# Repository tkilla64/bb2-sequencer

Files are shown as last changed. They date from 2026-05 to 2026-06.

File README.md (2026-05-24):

# bb2-sequencer
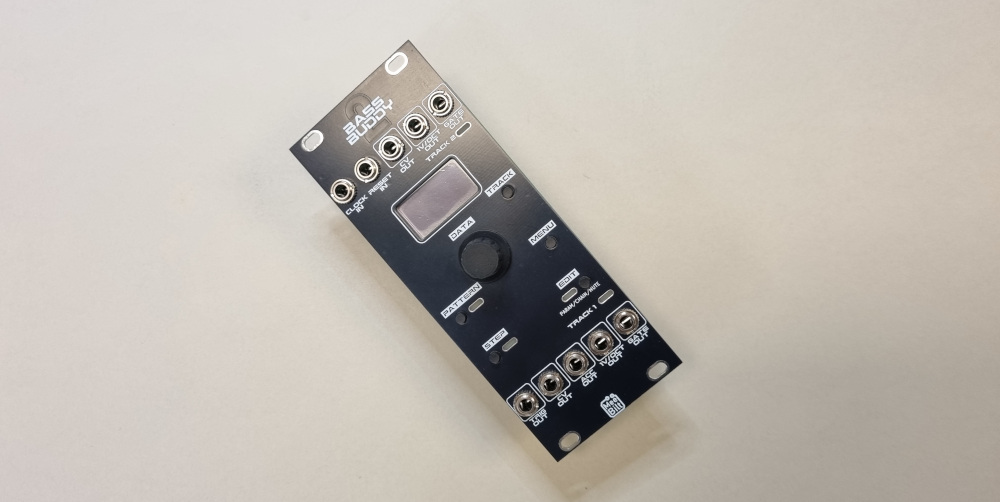
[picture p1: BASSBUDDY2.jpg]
bb2 image

BassBuddy2 Sequencer is a dual 16-step sequencer for Eurorack. It is designed to be used with the Erica Synths Bassline DIY, but any Eurorack synth-voice can be used.

### Inputs
CLOCK input with 1 clock-pulse per step the advance is made on the low-to-high transition of the signal.  
RESET input which resets the current pattern to step 1 at the low-to-high transition. RESET input can be reconfigured to a Clock for Track2 sequencer.

### Track1 Outputs
GATE output that is held high during the high period of the CLOCK input signal.  
1V/OCT output with note pitch voltage (0.0-4.916V, C-0 to B-4)  
VCF CV output with programmable voltage 0-5V  
ACCENT CV output with programmable 0-5V  
TRIG output programmable 5V pulse 

### Track2 Outputs
GATE output that is held high during the high period of the CLOCK input signal.  
1V/OCT output with note pitch voltage (0.0-4.916V, C-0 to B-4)  
VCF CV output with programmable voltage 0-5V   

### Steps and Patterns
A total of 60 patterns with pattern length 1-16 steps where each step have the following programmable functions:
 - Note pitch (or rest)
 - Tie note to next step
 - Slide to next step
 - VCF CV voltage

### User Interface
Consists of the 0.96" OLED, 5 pushbuttons, 5 LEDs and a rotary encoder with a pushbutton switch.

PATTERN, STEP and EDIT buttons selects and edits patterns. Possible to chain patterns.

TRACK button selects between tracks (sequencer).

MENU button accesses the following functions:
 - NEW: create a new empty pattern
 - SAVE: Save patterns and settings to EEPROM
 - LOAD: Load patterns and settings from EEPROM
 - COPY: Copy pattern
 - CLK:  Configure CLOCK and RESET
 - SEQ:  Set startup pattern after power on
 - CAL:  Calibrate the the dual-PWM outputs
 - TUN1: Output a note on 1V/OCT outputs
 - FACT: Reset patterns and settings to factory settings

### Supply
10-pin power connector:  
+12 VDC @ 60 mA  
-12 VDC @ 10 mA

### Dimensions
Height: 3U  
Width:  10HP  
Depth:  30 mm

### YouTube video
[Eurorack DIY: Bass Buddy II - Bigger and Better](https://youtu.be/oqoJV0XfK5c)

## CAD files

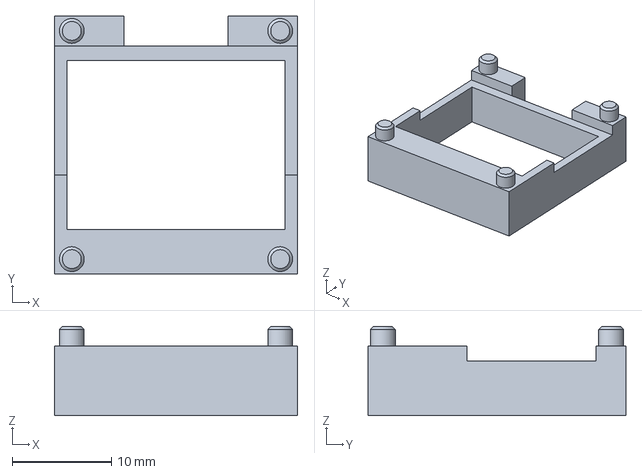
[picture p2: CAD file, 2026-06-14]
mech/OLED_bracket.FCStd
24.5 x 26.0 x 9.00 mm

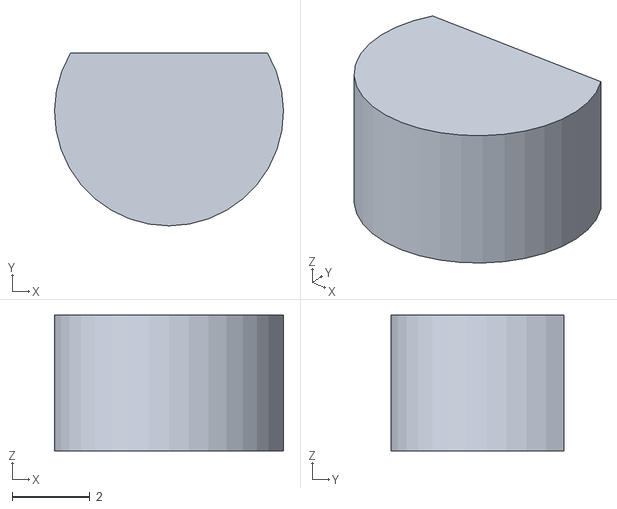
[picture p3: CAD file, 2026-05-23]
mech/shims_encoder_knob_v1.stl
5.90 x 4.45 x 3.50

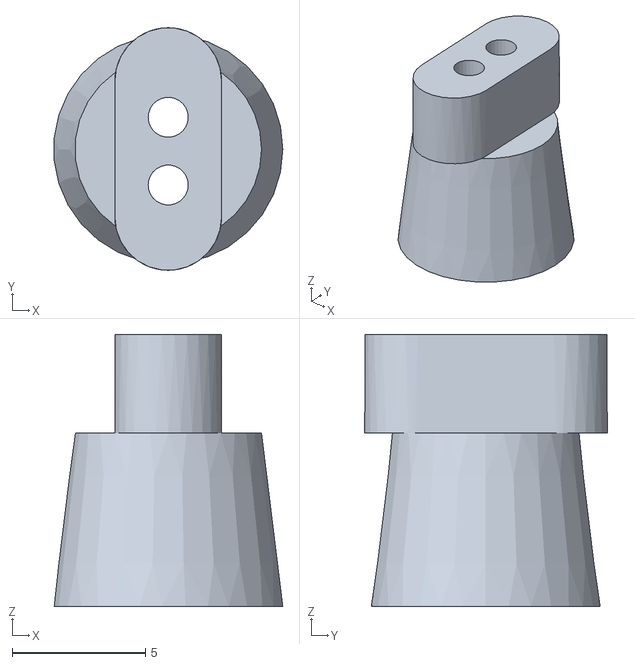
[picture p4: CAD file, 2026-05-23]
mech/2pin_LED_holder_v1.stl
8.57 x 9.10 x 10.2

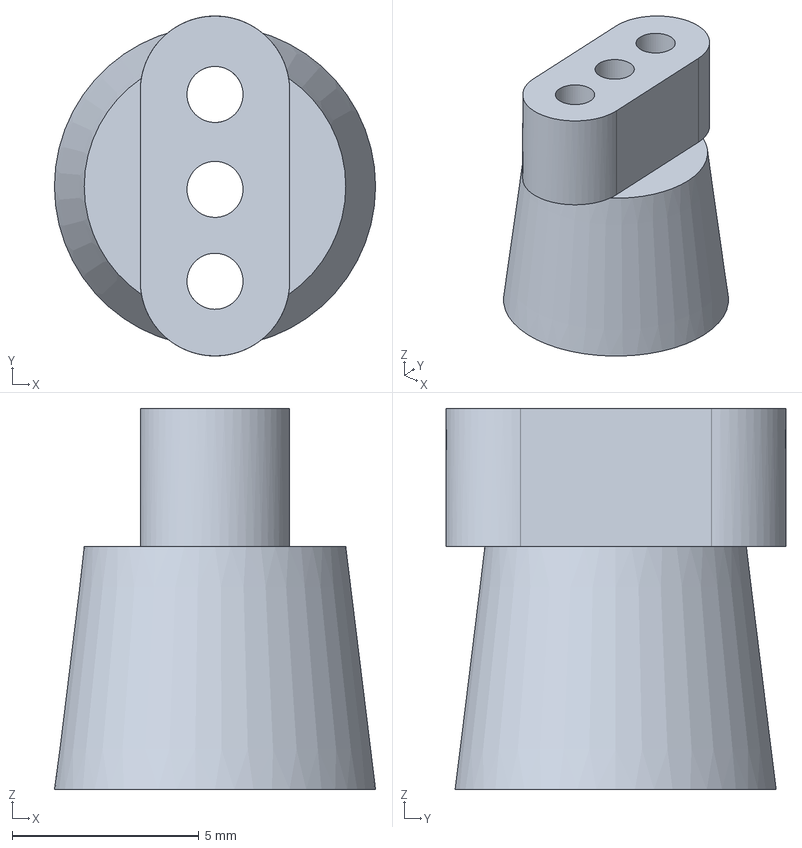
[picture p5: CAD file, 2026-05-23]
mech/3pin_LED_holder.FCStd
8.60 x 9.10 x 10.2 mm

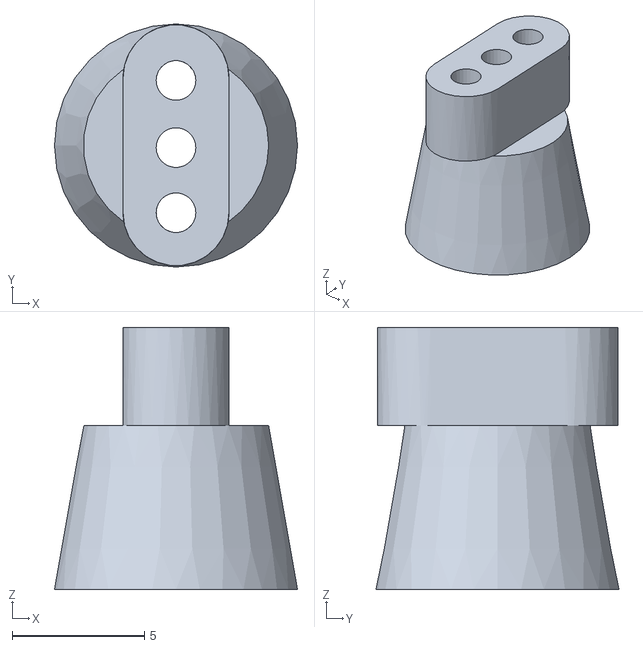
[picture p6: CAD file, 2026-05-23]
mech/3pin_LED_holder_v1.stl
9.19 x 9.19 x 9.90

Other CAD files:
mech/OLED_bracket_v1.stl
mech/shims_encoder_knob.FCStd
mech/2pin_LED_holder.FCStd

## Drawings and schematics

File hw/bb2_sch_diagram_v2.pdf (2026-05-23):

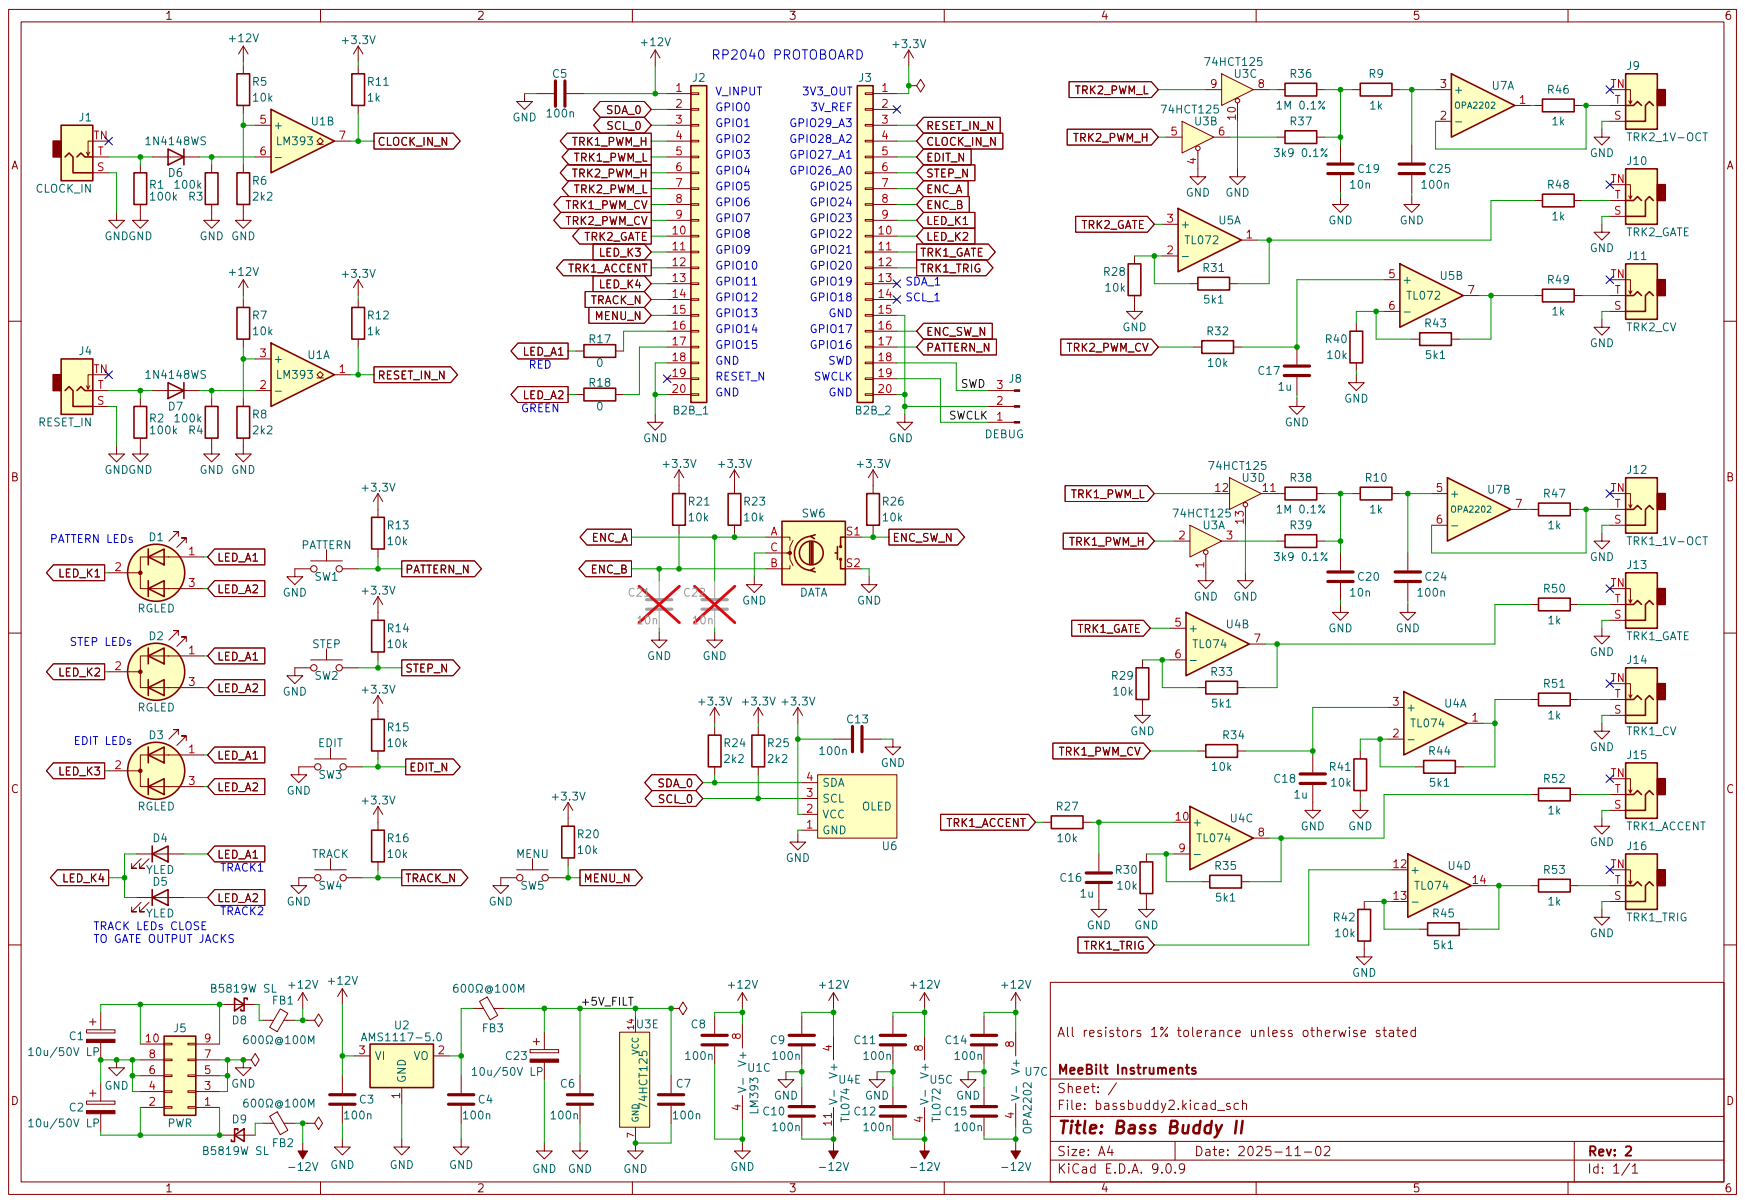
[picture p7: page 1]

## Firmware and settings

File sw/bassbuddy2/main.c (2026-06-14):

/**
 * @file main.c
 * 
 * Bass Buddy II (by Tommy Killander, tkilla64, MeeBilt):
 *
 * FEATURES:
 *  - CLOCK and RESET inputs 
 *  - Two tracks with separate outputs:
 *    * Track1: GATE, 1V/OCT, ACC, CV, TRIG
 *    * Track2: GATE, 1V/OCT, CV
 *  - 128x64 OLED Display
 *  - Control: 5 buttons and Encoder knob
 *  - EEPROM for calibration and parameter storage (4096 bytes)
 * 
 * IDE: Visual Studio Code with Raspberry Pi Pico SDK Extensions installed. 
 * 
 * TODO:
 *   * Add pulsewidth setting for Trig Out pulse
 *   * CV OUT LFO mode:
 *      - Tri, Saw, Random
 *      - per step or pattern repeat
 *   * Sequencer Gate control
 *   * Internal clock generation 1-255 BPM
 * 
 * BUGS: 
 *   * make sure pattern does not change during edit (turn off link)
 *   * not possible to bail out of CHAIN page with PATTERN or STEP
 *   * fix jitter in BPM calculation
 */

#include <stdio.h>
#include <stdint.h>
#include <string.h>
#include <math.h>
#include "pico/stdlib.h"
#include "pico/rand.h"
#include "hardware/irq.h"
#include "hardware/gpio.h"
#include "hardware/i2c.h"
#include "hardware/pwm.h"
#include "eeprom.h"
#include "pwm.h"
#include "switch.h"
#include "led.h"
#include "ssd1306.h"
#include "display.h"
#include "sequencer.h"

// Common definitions
#define SW_VER_MAJOR    1U      // software version 0-9
#define SW_VER_MINOR    22U     // software version 0-99
     
#define STARTUP_TIME    3000U   // ms for startup splash and LED POST cycle
#define GATE_OFF_MS     30      // Gate off time

#define SLIDE_STEP_MS   4       // time between each slide step
#define EXP_LUT_NO      20      // no of entries in Log LUT

#define MILLIVOLT_PER_NOTESTEP  83.334f // 1Volt per Octave standard

// Uncomment to get CPU load metrics for ISR and main loop
// The output will be execution time in micro-seconds
//#define MEAS_LOAD             // USB printf will affect performance
                                // so don't leave this on for production code :)

/*
 * Hardware Setup defines
 */

// Define IO pins
#define I2C_SDA1        18      // EEPROM I2C
#define I2C_SCL1        19      // EEPROM I2C
#define CLOCK_N         28      // Clock Input
#define RESET_N         29      // Reset Input

// MMI defines
const char notes[12][3] = { 
    "C-", "C#", "D-", "D#", 
    "E-", "F-", "F#", "G-", 
    "G#", "A-", "A#", "B-"
};

enum mmi_states {
    // this sysmenu items must be first and they must
    // also match with SYSMENU_ITEMS (see display.h)
    // and sys_menu_names (see display.c)
    m_sysmenu_new,          // create a new pattern
    m_sysmenu_load,         // reload pattern from EEPROM
    m_sysmenu_save,         // save pattern to EEPROM
    m_sysmenu_copy,         // copy pattern
    m_sysmenu_clock,        // trig/clock/reset settings
    m_sysmenu_seq,          // sequencer config
    m_sysmenu_cal_trk1,     // calibrate 1V/OCT output Track1
    m_sysmenu_cal_trk2,     // calibrate 1V/OCT output Track2
    m_sysmenu_tune_trk1,    // oscillator tuning Track1
    m_sysmenu_tune_trk2,    // oscillator tuning Track2
    m_sysmenu_factory_rst,  // Factory Reset
    // sysmenu stops here - see comment above

    m_main_status,          // Main Status window
    m_patt_menu_sel,        // Pattern select page
    m_step_menu_sel,        // Step select page
    m_edit_step_page,       // Edit step parameters
    m_edit_patt_link,       // Edit pattern link page
    m_edit_patt_cyc,        // Edit pattern cycles
    m_edit_patt_reset,      // Edit pattern reset
    m_sys_menu_sel,         // Sysmenu select spinner
    m_sys_cal_trk1_offs,    // calibrate offset page Track1
    m_sys_cal_trk1_gain,    // calibrate gain page Track1
    m_sys_cal_trk2_offs,    // calibrate offset page Track2
    m_sys_cal_trk2_gain,    // calibrate gain page Track2
    m_sys_tune_trk1,        // oscillator tuning page Track1
    m_sys_tune_trk2,        // oscillator tuning page Track2
    m_sys_new_ptn,          // new pattern select
    m_sys_new_steps,        // no of steps select
    m_sys_new_note,         // fill with note
    m_sys_copy_ptn,         // copy pattern select
    m_sys_copy_target,      // target pattern select
    m_sys_copy_transpose,   // transpose option
    m_sys_save_dialog,      // Save patterns page
    m_sys_load_dialog,      // Load patterns page
    m_seq_trk1_ptn,         // Track1 startup pattern
    m_seq_trk2_ptn,         // Track2 startup pattern
    m_clk_clock_pol,        // CLK polarity select
    m_clk_reset_pol,        // RESET polarity select
    m_clk_mode_sel,         // Clock mode select
    m_sys_factory_reset     // Factory reset select  
};

// Edit parameters
enum edit_params {
    e_edit_noteval,
    e_edit_tied,
    e_edit_slide,
    e_edit_trig,
    e_edit_accent,
    e_edit_cv,
    e_last_param,
};

const char edit_par[e_last_param][8] = {
    "Note",
    "Tied",
    "Slide",
    "TrigOut",
    "Accent",
    "CV Out",
};

// Slide exponential decay look-up table for simulating capacitor charge/discharge
const float exp_lut[EXP_LUT_NO] = {
    0.221f,     // 0.25t
    0.393f,     // 0.5t
    0.528f,     // 0.75t
    0.632f,     // 1t
    0.713f,     // 1.25t
    0.777f,     // 1.5t
    0.826f,     // 1.75t
    0.865f,     // 2t
    0.895f,     // 2.25t
    0.918f,     // 2.5t
    0.936f,     // 2.75t
    0.950f,     // 3t
    0.961f,     // 3.25t
    0.971f,     // 3.5t
    0.976f,     // 3.75t
    0.982f,     // 4t
    0.986f,     // 4.25t
    0.989f,     // 4.5t
    0.991f,     // 4.75t
    0.993f,     // 5t
};

// storage for calibration data and user settings
struct nonVolCal CAL; 
struct nonVolPar PAR;

// Prototypes
void compose_top_row(char *strline0);
void compose_sequencer_data(uint track, char *strline1, char*strline2);
void select_edit_parameter(uint sel_pattern, uint sel_edit_step, uint sel_param);
bool fequal(float a, float b, float epsilon);
void set_gate_output(uint track, uint value);
void set_trig_output(bool value);
uint16_t note_to_cv(uint track, uint8_t note);
void get_note_string(char *string, uint8_t note);
void goto_sys_menu(uint *mmi, uint *sysmenu);
void goto_patt_sel_menu(uint *mmi, uint8_t *sel_pattern);

/*
 * Sequencer Core
 */

uint8_t slide_step[2];      // used for slide lut index
uint16_t buff_cv[2];        // buffered CV value used to calculate slide
int32_t slide_cv[2];        // travel CV for slide to the next note
uint8_t curr_pattern[2];    // current pattern that is played
uint8_t curr_step[2];       // current step
uint8_t curr_repeat[2];     // repeat counter
uint8_t next_pattern[2];    // next pattern to play at end of pattern
uint8_t repeat_pattern[2];  // how many times to repeat the pattern
uint8_t reset_pattern[2];   // pattern to play when RESET
bool track_enable[2] =      // sequencer enable
    { false, false };
bool slide_enable[2] =      // slide to next step
    { false, false };
bool tuning_enable = false; // tuning mode

// advance sequencer to the next step 
void seq_advance_step(uint seq, bool tick)
{
    if (tick && !tuning_enable) { // tick...
        if (PAR.pattern[curr_pattern[seq]][curr_step[seq]].accent & SLIDE_MASK) {   // check is slide is activated
            slide_step[seq] = 0;
            slide_enable[seq] = true;
            slide_cv[seq] = (int32_t) (note_to_cv(seq, PAR.pattern[curr_pattern[seq]][curr_step[seq]].note & NOTE_MASK) - (int32_t) buff_cv[seq]);
        }
        else {    // Set 1V/OCT out directly if no slide
            buff_cv[seq] = note_to_cv(seq, PAR.pattern[curr_pattern[seq]][curr_step[seq]].note & NOTE_MASK);
            dual_pwm_set_out(seq, buff_cv[seq]);
        }
        // GATE_OUT = On (if note is not rest)
        if ((PAR.pattern[curr_pattern[seq]][curr_step[seq]].note & NOTE_MASK) > 0) {
            if (track_enable[seq]) {
                set_gate_output(seq, true);
                if (PAR.pattern[curr_pattern[seq]][curr_step[seq]].accent & TIED_MASK) 
                    if (seq == 0)
                        led_set_status(LED_TRACK1, red);
                    else
                        led_set_status(LED_TRACK2, green);
                else
                    if (seq == 0)
                        led_set_status(LED_TRACK1, red_fade);
                    else
                        led_set_status(LED_TRACK2, green_fade);
            }
        }
        // Set ACCENT out and TRIG out for track1 only
        if (seq == 0) {
            trk1_accent_set_out((uint8_t)(PAR.pattern[curr_pattern[seq]][curr_step[seq]].accent & ACC_MASK) * 17);
            set_trig_output(PAR.pattern[curr_pattern[seq]][curr_step[seq]].accent & TRIG_MASK);
        }
        // Set CV out
        pwm_cv_set_out(seq, PAR.pattern[curr_pattern[seq]][curr_step[seq]].vcf_cv);
    }
    else {      // ...tock
        // GATE OUT = Off (if not tied note)
        if (!(PAR.pattern[curr_pattern[seq]][curr_step[seq]].accent & TIED_MASK)) {
            set_gate_output(seq, false);
        }
        // Advance step
        curr_step[seq]++;
        // Check if at end of pattern
        if (curr_step[seq] >= (PAR.pattern_prop[curr_pattern[seq]] & PTRN_LEN_MASK)+1) {
            curr_repeat[seq]++;
            if (curr_repeat[seq] >= repeat_pattern[seq]) {
                curr_repeat[seq] = 0;
                // Link to self, just repeat pattern
                if (next_pattern[seq] == curr_pattern[seq]) {
                    next_pattern[seq] = ((PAR.pattern_prop[curr_pattern[seq]] & PTRN_CHAIN_MASK) >>5);
                }
            }
            curr_step[seq] = 0;
            curr_pattern[seq] = next_pattern[seq];
            repeat_pattern[seq] = ((PAR.pattern_prop[curr_pattern[seq]] & PTRN_REPT_MASK) >>11)+1;  
            if (((PAR.pattern_prop[curr_pattern[seq]] & PTRN_RESET_MASK) >>4))
                reset_pattern[seq] = curr_pattern[seq];
        }
    }
}

// set current pattern
void seq_set_pattern(uint seq, uint pattern)
{
    curr_pattern[seq] = pattern;
    next_pattern[seq] = pattern;
    curr_step[seq] = 0;
    curr_repeat[seq] = 0;
    repeat_pattern[seq] = ((PAR.pattern_prop[pattern] & PTRN_REPT_MASK) >>11)+1;
    if (((PAR.pattern_prop[pattern] & PTRN_RESET_MASK) >>4))
        reset_pattern[seq] = pattern;
}

// set next pattern
void seq_set_next_pattern(uint seq, uint pattern)
{
    next_pattern[seq] = pattern;
}

// calculate and set the CV output from the charge lookup table. called if slide is active
void seq_next_slide_step(uint seq)
{
    dual_pwm_set_out(seq, (uint16_t)((int32_t)buff_cv[seq] + (int32_t)((float) slide_cv[seq] * exp_lut[slide_step[seq]])));
    if (slide_step[seq] < EXP_LUT_NO-1)     // check if we reached end of table
        slide_step[seq]++;
    else {
        slide_enable[seq] = false;
        buff_cv[seq] = note_to_cv(seq, PAR.pattern[curr_pattern[seq]][curr_step[seq]].note & NOTE_MASK);
        dual_pwm_set_out(seq, note_to_cv(seq, PAR.pattern[curr_pattern[seq]][curr_step[seq]].note & NOTE_MASK));
    }
}

/*
 * ISRs
 */

#ifdef MEAS_LOAD     
volatile uint64_t timer_isr_time_us,  main_time_us; 
volatile uint64_t max_isr_time_us = 0;
volatile absolute_time_t t_entry, m_entry;
#endif

volatile uint16_t bpm_set_tempo1 = 0xFFFF;
volatile uint16_t bpm_set_tempo2 = 0xFFFF;
volatile uint16_t bpm_timer1 = 0;
volatile uint16_t bpm_timer2 = 0;
volatile uint32_t timer_counter = 0;
volatile bool ext_clock_fired1 = false;
volatile bool ext_clock_fired2 = false;
volatile bool reset_fired = false;
volatile uint8_t sel_seqencer = TRK1;
static uint64_t ext_clock_us1;
static uint64_t ext_clock_us2;
static absolute_time_t c_entry1;
static absolute_time_t c_entry2;

// Timer Interrupt Handler (1ms period time)
// Main scheduler for all concurrent activities; cycle through the LED matrix,
// poll the rotary encoder and the buttons, service slide and the sequencers.
bool on_repeating_timer_expired(struct repeating_timer *t) {
#ifdef MEAS_LOAD     
    t_entry = get_absolute_time();
#endif
    if ((timer_counter % LED_CYCLE) == 0)           // cycle through all LEDs and update states 
        led_cycle_matrix();

    if ((timer_counter % ENC_POLL) == 0)            // Readout the encoder knob value
        encoder_poll();

    if ((timer_counter % BUTTON_POLL) == 0)         // debounce all buttons and update event-mask
        buttons_poll();

    if (timer_counter % SLIDE_STEP_MS == 0) {       // check if slide is needs update
        if (slide_enable[TRK1])
            seq_next_slide_step(TRK1);

        if (slide_enable[TRK2])
            seq_next_slide_step(TRK2);
    }

    // service track 1 sequencer
    if (PAR.tempo == 0 && ext_clock_fired1) {   // external clock?
        ext_clock_fired1 = false;
        bpm_timer1 = bpm_set_tempo1;
        seq_advance_step(TRK1, true);           // tick...
    }    
    if (bpm_timer1 == GATE_OFF_MS) {
        seq_advance_step(TRK1, false);          // ...tock
    }
    bpm_timer1--;

    // service track 2 sequencer
    if (PAR.tempo == 0 && ext_clock_fired2) {   // external clock?
        ext_clock_fired2 = false;
        bpm_timer2 = bpm_set_tempo2;
        seq_advance_step(TRK2, true);           // tick...
    }    
    if (bpm_timer2 == GATE_OFF_MS) {
        seq_advance_step(TRK2, false);          // ...tock
    }
    bpm_timer2--;

    if (reset_fired) {                              // external reset
        seq_set_pattern(TRK1, reset_pattern[TRK1]);
        seq_set_pattern(TRK2, reset_pattern[TRK2]);
        reset_fired = false;
    }
    timer_counter++;
#ifdef MEAS_LOAD     
    timer_isr_time_us = absolute_time_diff_us(t_entry, get_absolute_time());
    if (timer_isr_time_us > max_isr_time_us)
        max_isr_time_us = timer_isr_time_us;
#endif
    return true;
}

// GPIO edge triggered interrupt handler
// Note that the trig GPIO inputs are inverted by HW design
void on_edge_event(uint gpio, uint32_t events) 
{
    // CLK trig depending on CLK polarity setting 
    if ((gpio == CLOCK_N && (events & GPIO_IRQ_EDGE_FALL) && !PAR.clock_pol) || 
        (gpio == CLOCK_N && (events & GPIO_IRQ_EDGE_RISE) && PAR.clock_pol)) {
        ext_clock_fired1 = true;        // clock Track1
        ext_clock_us1 = absolute_time_diff_us(c_entry1, get_absolute_time());
        c_entry1 = get_absolute_time();
        bpm_set_tempo1 = ext_clock_us1 / 1000;
        if (PAR.clock_func == 0) {      // also clock Track2 ?
            ext_clock_fired2 = true;
            ext_clock_us2 = absolute_time_diff_us(c_entry2, get_absolute_time());
            c_entry2 = get_absolute_time();
            bpm_set_tempo2 = ext_clock_us2 / 1000;
        }
    }
    // RESET trig depending on RESET polarity setting
    if ((gpio == RESET_N && (events & GPIO_IRQ_EDGE_FALL) && !PAR.reset_pol) || 
        (gpio == RESET_N && (events & GPIO_IRQ_EDGE_RISE) && PAR.reset_pol)) {       
        if (PAR.reset_func == 0)        // reset tracks ?
            reset_fired = true;
        else {                          // or clock Track2
            ext_clock_fired2 = true;
            ext_clock_us2 = absolute_time_diff_us(c_entry2, get_absolute_time());
            c_entry2 = get_absolute_time();
            bpm_set_tempo2 = ext_clock_us2 / 1000;
        }
    }
}

/*
 * MAIN SETUP:
 *
 * The setup section of main() initialises all the hardware peripherials 
 * and local variables. It reads non-volatile EEPROM areas into RAM areas
 * CAL and PAR and sets up the sequencer startup parameters.
 */
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

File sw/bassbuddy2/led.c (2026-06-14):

/** 
* @file led.c
* 
* functions for handling switches and buttons
*
*/

#include <stdio.h>
#include <stdint.h>
#include "pwm.h"
#include "led.h"

// Setup LED states
static led_matrix_t led_pairs[MAX_LED_PAIRS] = {
    { off, 0, 0, 0, LED_K1 }, // PATTERN
    { off, 0, 0, 0, LED_K2 }, // STEP
    { off, 0, 0, 0, LED_K3 }, // EDIT
    { off, 0, 0, 0, LED_K4 }, // TRACK1
    { off, 0, 0, 0, LED_K4 }  // TRACK2
};

// init LED GPIOs
void led_init_gpios(void) {
    gpio_init(LED_K1);
    gpio_set_dir(LED_K1, GPIO_OUT);
    gpio_set_drive_strength(LED_K1, GPIO_DRIVE_STRENGTH_12MA);
    gpio_init(LED_K2);
    gpio_set_dir(LED_K2, GPIO_OUT);
    gpio_set_drive_strength(LED_K2, GPIO_DRIVE_STRENGTH_12MA);
    gpio_init(LED_K3);
    gpio_set_dir(LED_K3, GPIO_OUT);
    gpio_set_drive_strength(LED_K3, GPIO_DRIVE_STRENGTH_12MA);
    gpio_init(LED_K4);
    gpio_set_dir(LED_K4, GPIO_OUT);
    gpio_set_drive_strength(LED_K4, GPIO_DRIVE_STRENGTH_12MA);
}

// cycle through LED matrix, called periodically
// from the timer ISR
volatile int cycle = 0;
void led_cycle_matrix(void) {
    // activate cathone pin for current cycle, but since the 
    // TRACK1 and TRACK2 LEDs share the same cathode pin, 
    // we need to activate it for both cycles. 
    for (int i = 0 ; i < MAX_LED_PAIRS ; i++) {
        gpio_put(led_pairs[i].led_cathode_pin, 
            (i == cycle) ? 0 : (cycle >= LED_TRACK1 && i >= LED_TRACK1) ? 0 : 1);
    }
    switch (led_pairs[cycle].led_mode) {
        case green_fade:
            led_pairs[cycle].curr_red_intensity = 0;
            led_pairs[cycle].curr_grn_intensity = 255;
            led_pairs[cycle].direction = -1;
            led_pairs[cycle].led_mode = green_fade_run;
            break;
        case green_fade_run:
            if (led_pairs[cycle].curr_grn_intensity > LED_RAMP_STEP) {
                led_pairs[cycle].curr_grn_intensity -= LED_RAMP_STEP;
            } else {
                led_pairs[cycle].led_mode = off;
                led_pairs[cycle].direction = 0;
            }
            break;
        case red_fade:
            led_pairs[cycle].curr_red_intensity = 255;
            led_pairs[cycle].curr_grn_intensity = 0;
            led_pairs[cycle].direction = -1;
            led_pairs[cycle].led_mode = red_fade_run;
            break;
        case red_fade_run:    
            if (led_pairs[cycle].curr_red_intensity > LED_RAMP_STEP) {
                led_pairs[cycle].curr_red_intensity -= LED_RAMP_STEP;
            } else {
                led_pairs[cycle].led_mode = off;
                led_pairs[cycle].direction = 0;
            }
            break;        
        case amber_fade:
            led_pairs[cycle].curr_red_intensity = 255;
            led_pairs[cycle].curr_grn_intensity = 255;
            led_pairs[cycle].direction = -1;
            led_pairs[cycle].led_mode = amber_fade_run;
            break;
        case amber_fade_run:
            if (led_pairs[cycle].curr_red_intensity > LED_RAMP_STEP) {
                led_pairs[cycle].curr_red_intensity -= LED_RAMP_STEP;
                led_pairs[cycle].curr_grn_intensity -= LED_RAMP_STEP;
            } else {
                led_pairs[cycle].led_mode = off;
                led_pairs[cycle].direction = 0;
            }
            break;
        case off:
            led_pairs[cycle].curr_red_intensity = 0;
            led_pairs[cycle].curr_grn_intensity = 0;            
            break;
        case green:
            led_pairs[cycle].curr_red_intensity = 0;
            led_pairs[cycle].curr_grn_intensity = 255;
            break;
        case amber:
            led_pairs[cycle].curr_red_intensity = 255;
            led_pairs[cycle].curr_grn_intensity = 255;
            break;
        case red:
            led_pairs[cycle].curr_red_intensity = 255;
            led_pairs[cycle].curr_grn_intensity = 0;
        case pulsing_green:
        case pulsing_red_amber:
        default:
            break;
    }
    // update LED PWMs, note that TRACK LEDs are both the same color
    led_a1_set_out((cycle >= LED_TRACK1) 
        ? led_pairs[cycle].curr_red_intensity 
        : (led_pairs[cycle].curr_red_intensity/RLED_INT_RATIO));
    led_a2_set_out(led_pairs[cycle].curr_grn_intensity);
    cycle++;
    cycle %= MAX_LED_PAIRS;
}

void led_set_status(int led_id, uint8_t led_mode) {
    led_pairs[led_id].led_mode = led_mode;
}

void led_post_cycle(int delay) {
    for (int cyc=0 ; cyc < post_last_cycle ; cyc++) {
        switch (cyc) {
            case track2_on:
                led_set_status(LED_TRACK2, green);
                break;

            case track1_on:
                led_set_status(LED_TRACK1, red);
                break;

            case edit_green:
                led_set_status(LED_EDIT, green);
                break;

            case step_green:
                led_set_status(LED_STEP, green);
                break;

            case pattern_green:
                led_set_status(LED_PATTERN, green);
                break;

            case edit_red:
                led_set_status(LED_EDIT, red);
                break;

            case step_red:
                led_set_status(LED_STEP, red);
                break;

            case pattern_red:
                led_set_status(LED_PATTERN, red);
                break;

           case track2_off:
                led_set_status(LED_TRACK2, off);
                break;

            case track1_off:
                led_set_status(LED_TRACK1, off);
                break;

            case step_off:
                led_set_status(LED_STEP, off);
                break;

            case edit_off:
                led_set_status(LED_EDIT, off);
                break;

            case pattern_off:
                led_set_status(LED_PATTERN, off);
                break;

            default:
            break;
        }
        sleep_ms(delay/post_last_cycle);
    }
}

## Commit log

2026-05-23 Added bassbuddy2 sequencer
    The following have been added:
    - Gerbers, ibom, and schematic diagram for the main board
    - Gerbers for the PCB panel
    - 3D parts (FreeCAD and .stl files)
    - Source code V1.21 for the RP2040 (VSC + Pico extensions)
    - Flashfile v1.21
    [2pin_LED_holder.FCStd, 2pin_LED_holder_v1.stl, 3pin_LED_holder.FCStd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]
2026-06-14 Firmware update 1.22
    - added POST cycle for LEDs
    - updated uf2 flashfile
2026-06-14 Added OLED bracket
    - added OLED Bracket FreeCad and .stl files
    - cleaned up obsolete archive files
    [OLED_bracket.FCStd, OLED_bracket_v1.stl]
